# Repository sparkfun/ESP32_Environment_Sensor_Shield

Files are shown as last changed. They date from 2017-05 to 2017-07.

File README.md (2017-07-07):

SparkFun ESP32 Environment Sensor Shield
========================================

SparkFun ESP32 Environment Sensor Shield

[*SparkFun ESP32 Thing Environment Sensor Shield (DEV-14153)*](https://www.sparkfun.com/products/14153)

The SparkFun ESP32 Thing Environment Sensor Shield provides sensors and hookups for monitoring environmental conditions. While incorporating three sensors capable of measuring five different environmental variables as well as providing connections for several other sensors, this sensor shield creates the best way to make your ESP32 Thing more accurate than your local weatherman!

Repository Contents
-------------------

* **/Documentation** - Data sheets, additional product information
* **/Firmware** - Example code 
* **/Hardware** - Eagle design files (.brd, .sch)
* **/Production** - Production panel files (.brd)

Version History
---------------
* [v_H1.0](https://github.com/sparkfun/ESP32_Environment_Sensor_Shield/tree/v_H1.0) - Initial release

License Information
-------------------

This product is _**open source**_! 

Please review the LICENSE.md file for license information. 

If you have any questions or concerns on licensing, please contact techsupport@sparkfun.com.

Distributed as-is; no warranty is given.

- Your friends at SparkFun.

_<COLLABORATION CREDIT>_

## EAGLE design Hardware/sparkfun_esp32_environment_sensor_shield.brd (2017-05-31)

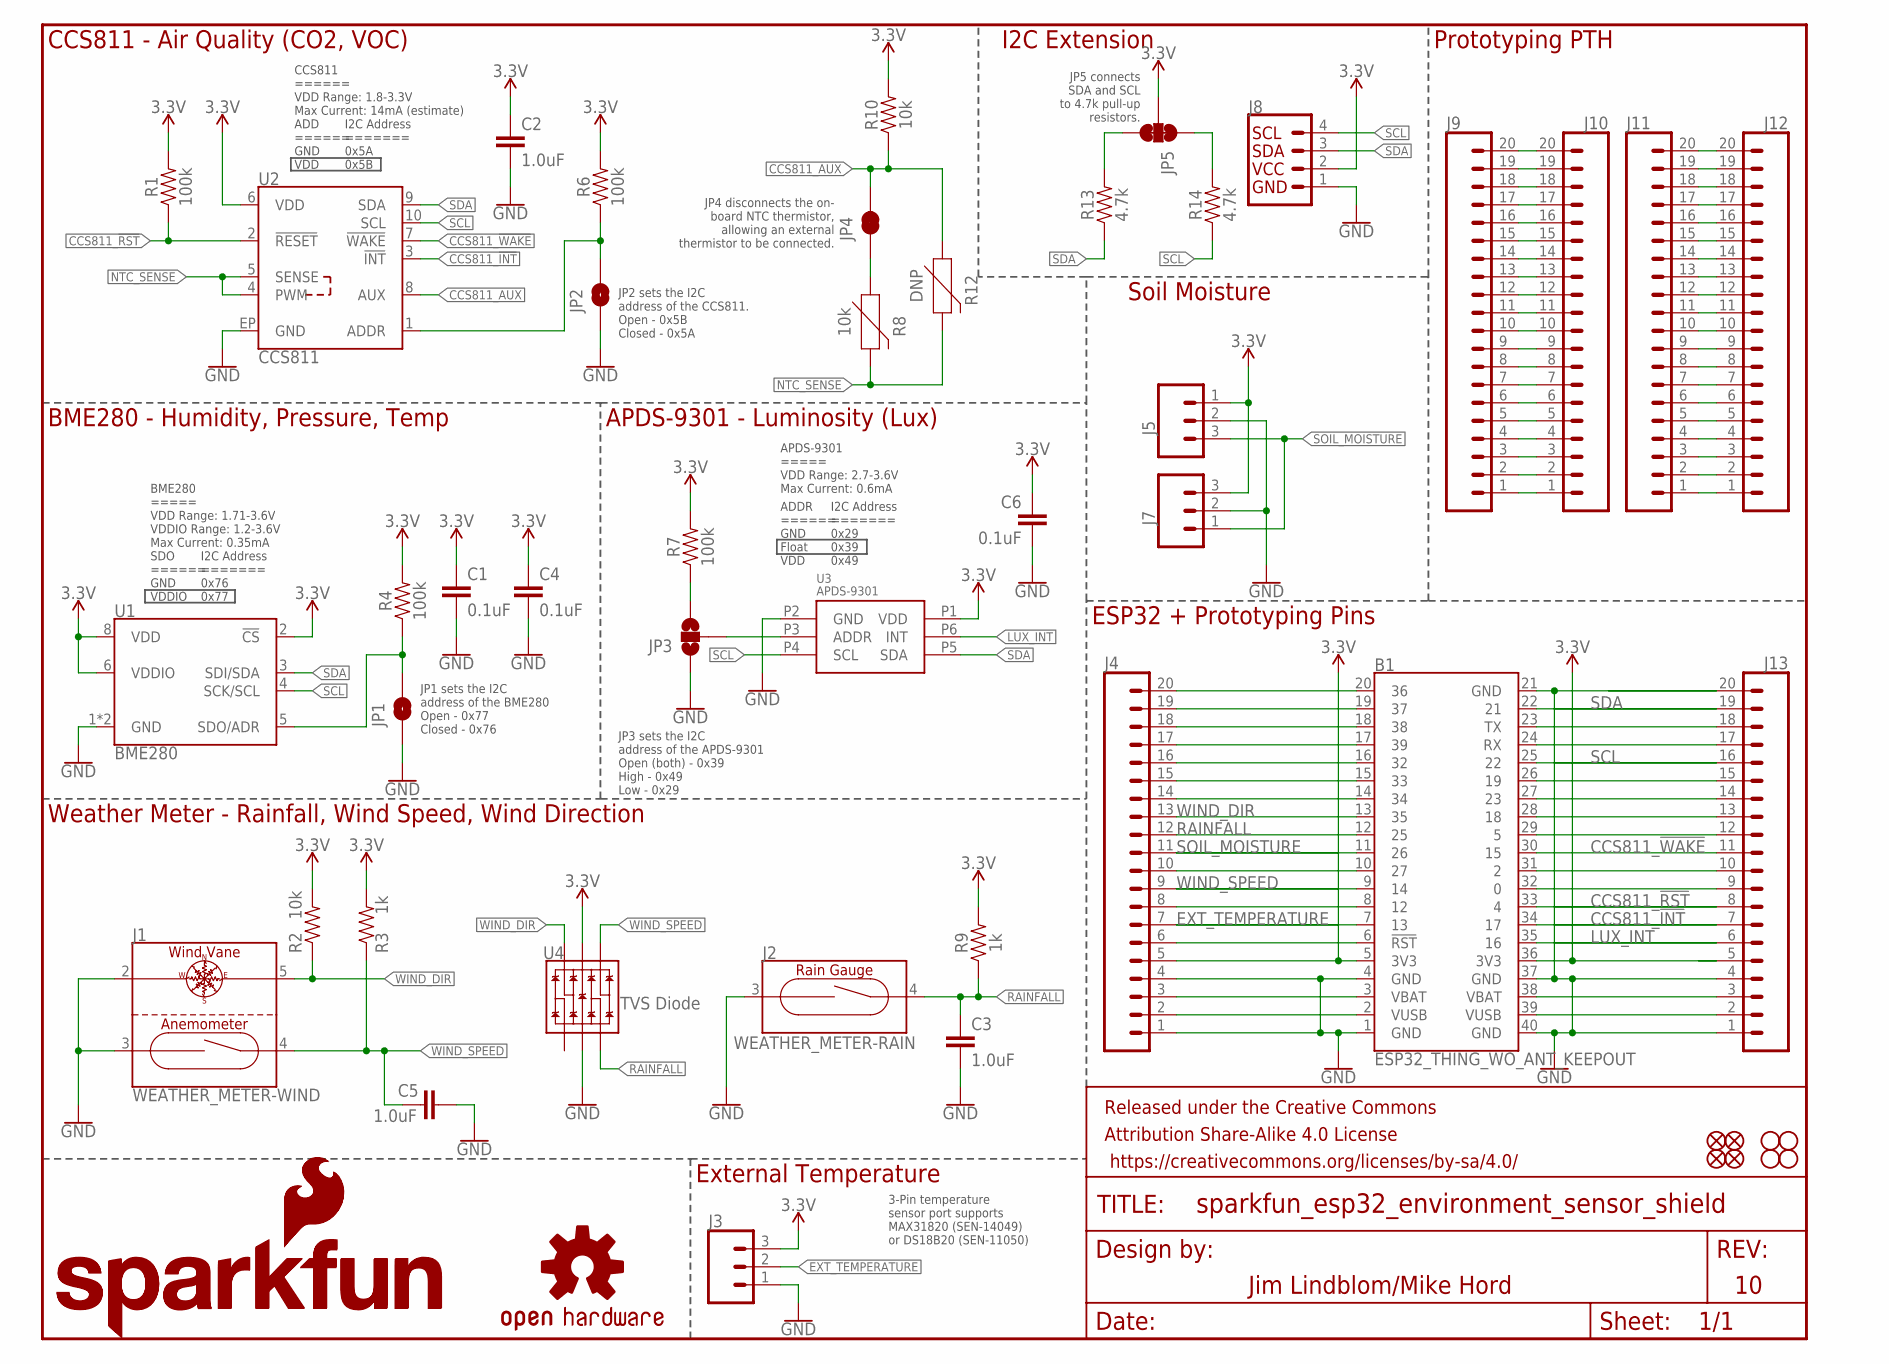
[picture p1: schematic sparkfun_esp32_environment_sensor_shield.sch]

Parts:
B1: ESP32_THING_WO_ANT_KEEPOUT; ESP32_THING_NO_ANT
C1, C4, C6: 0.1uF; 0603
C2, C3, C5: 1.0uF; 0603
FD1, FD2, FD3, FD4: FIDUCIAL1X2; FIDUCIAL-1X2
FRAME1: FRAME-LETTER; CREATIVE_COMMONS
H1, H2, H3, H4: STAND-OFF
J1: WEATHER_METER-WIND; RJ11-6
J2: WEATHER_METER-RAIN; RJ11-6
J3, J5: CONN_03; 1X03
J4, J9, J10, J11, J12, J13: CONN_20NOSILK; 1X20_NOSILK
J7: CONN_03SCREW-NS; SCREWTERMINAL-3.5MM-3-NS
J8: I2C_STANDARD; 1X04
JP1, JP2: JUMPER-SMT_2_NO_SILK; SMT-JUMPER_2_NO_SILK
JP3: JUMPER-SMT_3_NO_SILK; SMT-JUMPER_3_NO_SILK
JP4: JUMPER-SMT_2_NC_TRACE_SILK; SMT-JUMPER_2_NC_TRACE_SILK
JP5: JUMPER-SMT_3_2-NC_TRACE_SILK; SMT-JUMPER_3_2-NC_TRACE_SILK
LOGO1: SFE_LOGO_NAME.1_INCH; SFE_LOGO_NAME_.1
LOGO2: SFE_LOGO_NAME_FLAME.1_INCH; SFE_LOGO_NAME_FLAME_.1
LOGO3: SFE_LOGO_FLAME.1_INCH; SFE_LOGO_FLAME_.1
LOGO4: OSHW-LOGOS; OSHW-LOGO-S
R1, R4, R6, R7: 100k; 0603
R2, R8, R10: 10k; 0603
R3, R9: 1k; 0603
R12: DNP; AXIAL-0.1
R13, R14: 4.7k; 0603
U1: BME280; LGA-8-2.5X2.5
U2: CCS811; LGA10-2.7X4.0MM
U3: APDS-9301; CHIPLED-6
U4: TVS Diode; SOT-23-6

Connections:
3.3V: B1.5 (3V3), B1.36 (3V3), C1.1, C2.1, C4.1, C6.1, J3.3, J4.5, J5.1, J7.3, J8.2, J13.5, JP5.2, R1.2, R2.2, R3.2, R4.2, R6.2, R7.2, R9.2, R10.2, U1.2 (!CS), U1.6 (VDDIO), U1.8 (VDD), U2.6 (VDD), U3.P1 (VDD), U4.5 (VCC)
ADDR_TSL2561: JP3.2, U3.P3 (ADDR)
CCS811_!INT!: B1.34 (17), J13.7, U2.3 (!INT!)
CCS811_!RST!: B1.33 (4), J13.8, R1.1, U2.2 (!RESET!)
CCS811_!WAKE!: B1.30 (15), J13.11, U2.7 (!WAKE!)
CCS811_ADDR: JP2.2, R6.1, U2.1 (ADDR)
CCS811_AUX: JP4.2, R10.1, R12.P$1 (1), U2.8 (AUX)
EXT_TEMPERATURE: B1.7 (13), J3.2, J4.7
GND: B1.1 (GND), B1.4 (GND), B1.21 (GND), B1.37 (GND), B1.40 (GND), C1.2, C2.2, C3.2, C4.2, C5.2, C6.2, J1.2 (DIR-1), J1.3 (ANN-1), J2.3 (1), J3.1, J4.1, J4.4, J5.2, J7.2, J8.1, J13.1, J13.4, J13.20, JP1.1, JP2.1, JP3.1, U1.1 (GND), U1.7 (GND), U2.EP (GND), U3.P2 (GND), U4.2 (VSS)
LUX_INT: B1.35 (16), J13.6, U3.P6 (INT)
unnamed: JP3.3, R7.1
unnamed: JP1.2, R4.1, U1.5 (SDO/ADR)
unnamed: JP4.1, R8.1
unnamed: JP5.3, R13.2
unnamed: JP5.1, R14.2
unnamed: B1.2 (VUSB), J4.2
unnamed: B1.3 (VBAT), J4.3
unnamed: B1.6 (!RST!), J4.6
unnamed: B1.10 (27), J4.10
unnamed: B1.14 (34), J4.14
unnamed: B1.15 (33), J4.15
unnamed: B1.16 (32), J4.16
unnamed: B1.17 (39), J4.17
unnamed: B1.18 (38), J4.18
unnamed: B1.19 (37), J4.19
unnamed: B1.20 (36), J4.20
unnamed: B1.39 (VUSB), J13.2
unnamed: B1.38 (VBAT), J13.3
unnamed: B1.32 (0), J13.9
unnamed: B1.31 (2), J13.10
unnamed: B1.8 (12), J4.8
unnamed: B1.29 (5), J13.12
unnamed: B1.28 (18), J13.13
unnamed: B1.27 (23), J13.14
unnamed: B1.26 (19), J13.15
unnamed: B1.24 (RX), J13.17
unnamed: B1.23 (TX), J13.18
unnamed: J11.1, J12.1
unnamed: J11.2, J12.2
unnamed: J11.3, J12.3
unnamed: J11.4, J12.4
unnamed: J11.5, J12.5
unnamed: J11.6, J12.6
unnamed: J11.7, J12.7
unnamed: J11.8, J12.8
unnamed: J11.9, J12.9
unnamed: J11.10, J12.10
unnamed: J11.11, J12.11
unnamed: J11.12, J12.12
unnamed: J11.13, J12.13
unnamed: J11.14, J12.14
unnamed: J11.15, J12.15
unnamed: J11.16, J12.16
unnamed: J11.17, J12.17
unnamed: J11.18, J12.18
unnamed: J11.19, J12.19
unnamed: J11.20, J12.20
unnamed: J9.1, J10.1
unnamed: J9.2, J10.2
unnamed: J9.3, J10.3
unnamed: J9.4, J10.4
unnamed: J9.5, J10.5
unnamed: J9.6, J10.6
unnamed: J9.7, J10.7
unnamed: J9.8, J10.8
unnamed: J9.9, J10.9
unnamed: J9.10, J10.10
unnamed: J9.11, J10.11
unnamed: J9.12, J10.12
unnamed: J9.13, J10.13
unnamed: J9.14, J10.14
unnamed: J9.15, J10.15
unnamed: J9.16, J10.16
unnamed: J9.17, J10.17
unnamed: J9.18, J10.18
unnamed: J9.19, J10.19
unnamed: J9.20, J10.20
NTC_SENSE: R8.2, R12.P$2 (2), U2.4 (PWM), U2.5 (SENSE)
RAINFALL: B1.12 (25), C3.1, J2.4 (2), J4.12, R9.1, U4.3 (IO2)
SCL: B1.25 (22), J8.4, J13.16, R14.1, U1.4 (SCK/SCL), U2.10 (SCL), U3.P4 (SCL)
SDA: B1.22 (21), J8.3, J13.19, R13.1, U1.3 (SDI/SDA), U2.9 (SDA), U3.P5 (SDA)
SOIL_MOISTURE: B1.11 (26), J4.11, J5.3, J7.1
WIND_DIR: B1.13 (35), J1.5 (DIR2), J4.13, R2.1, U4.6 (IO4)
WIND_SPEED: B1.9 (14), C5.1, J1.4 (ANN-2), J4.9, R3.1, U4.4 (IO3)

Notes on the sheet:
APDS-9301 ===== VDD Range: 2.7-3.6V Max Current: 0.6mA
ADDR ====== GND Float VDD
I2C Address ======= 0x29 0x39 0x49
BME280 ===== VDD Range: 1.71-3.6V VDDIO Range: 1.2-3.6V Max Current: 0.35mA
SDO ====== GND VDDIO
I2C Address ======= 0x76 0x77
CCS811 ====== VDD Range: 1.8-3.3V Max Current: 14mA (estimate)
ADD ====== GND VDD
I2C Address ======= 0x5A 0x5B
CCS811 - Air Quality (CO2, VOC)
BME280 - Humidity, Pressure, Temp
APDS-9301 - Luminosity (Lux)
Weather Meter - Rainfall, Wind Speed, Wind Direction
I2C Extension
Soil Moisture
Prototyping PTH
ESP32 + Prototyping Pins
External Temperature
JP2 sets the I2C address of the CCS811. Open - 0x5B Closed - 0x5A
JP1 sets the I2C address of the BME280 Open - 0x77 Closed - 0x76
JP3 sets the I2C address of the APDS-9301 Open (both) - 0x39 High - 0x49 Low - 0x29
JP4 disconnects the on- board NTC thermistor, allowing an external thermistor to be connected.
JP5 connects SDA and SCL to 4.7k pull-up resistors.
Jim Lindblom/Mike Hord
3-Pin temperature sensor port supports MAX31820 (SEN-14049) or DS18B20 (SEN-11050)

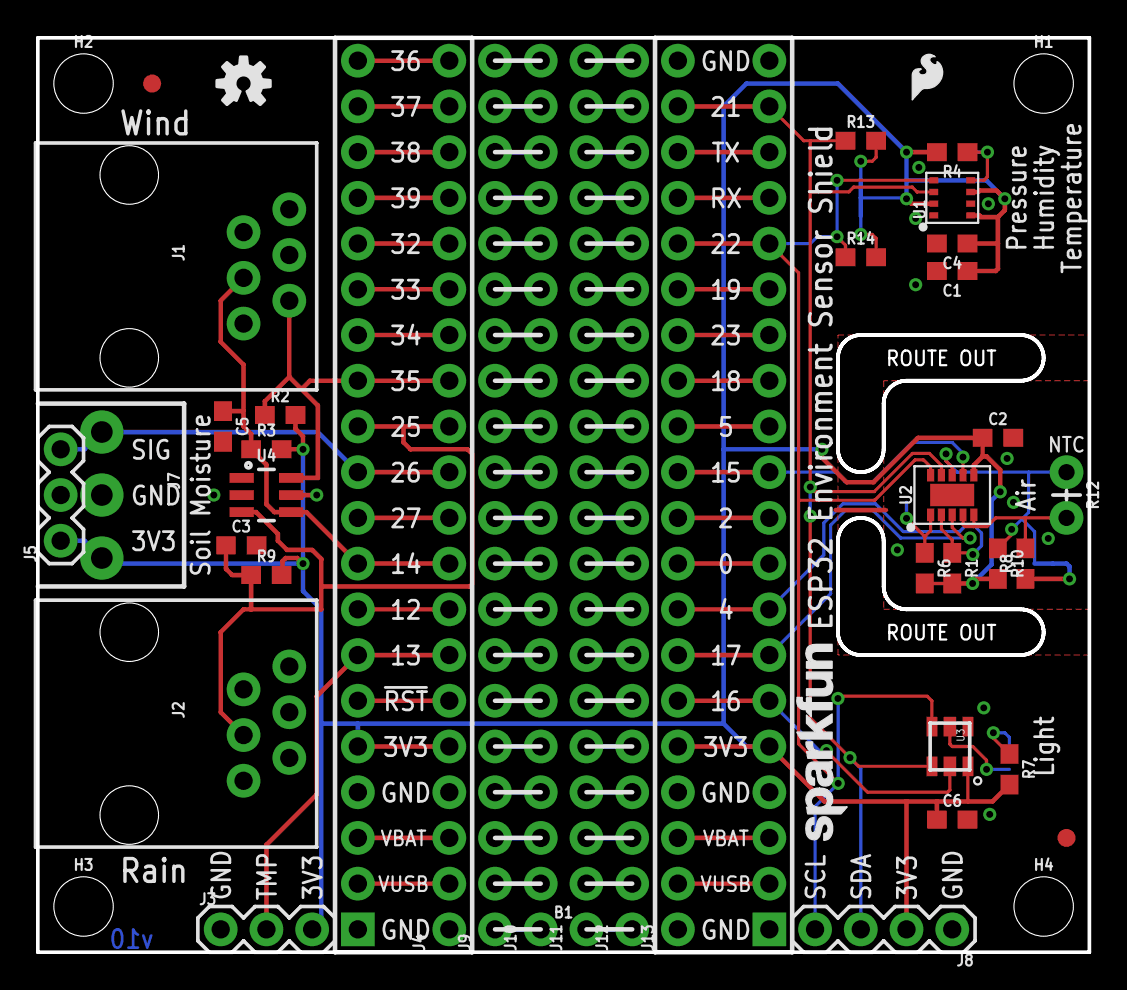
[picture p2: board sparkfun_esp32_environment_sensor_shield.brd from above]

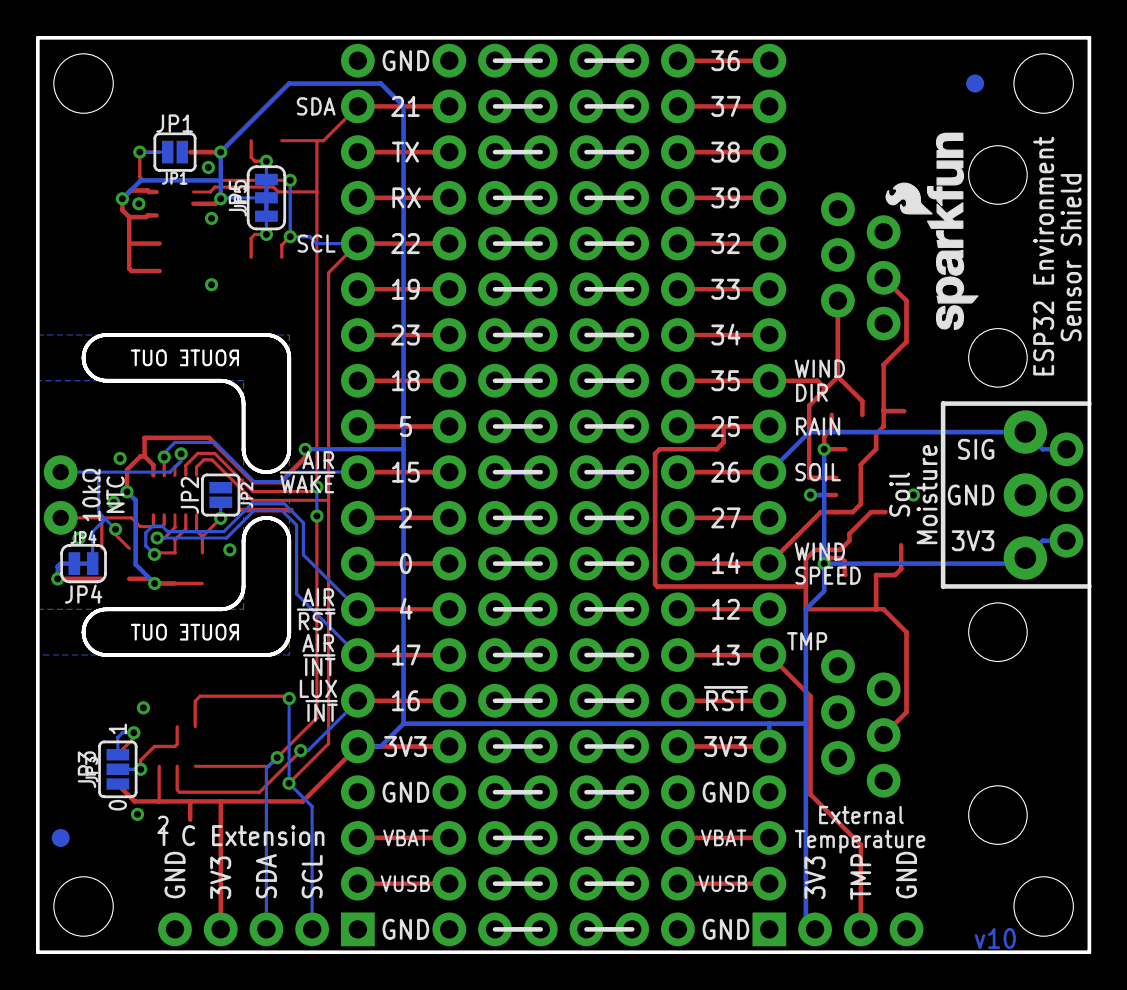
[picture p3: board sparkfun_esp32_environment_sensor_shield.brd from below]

Board: 2 copper layers, 58.4 x 50.8 mm, 53 parts (8 on the bottom side), 84 nets.

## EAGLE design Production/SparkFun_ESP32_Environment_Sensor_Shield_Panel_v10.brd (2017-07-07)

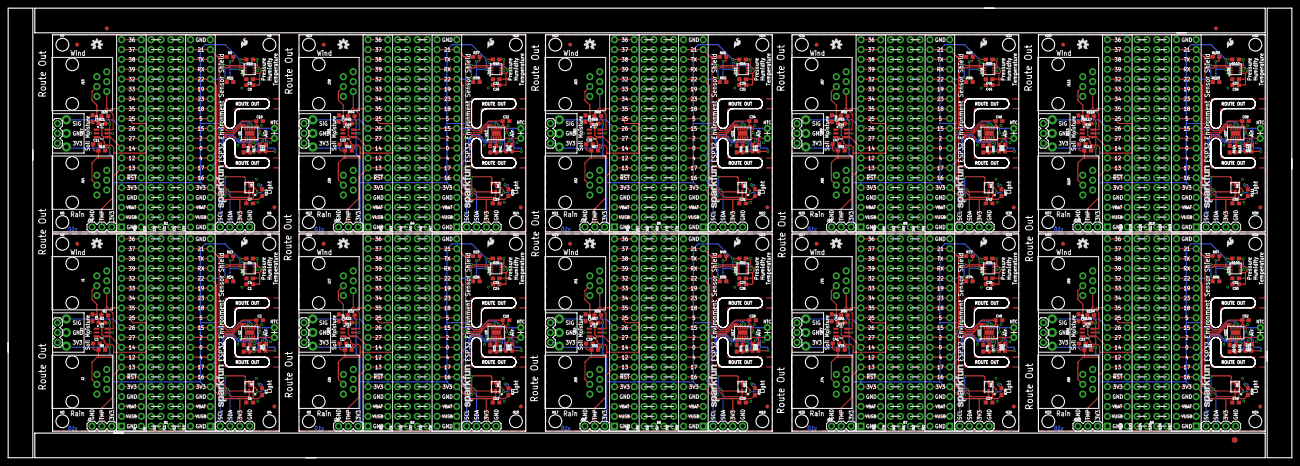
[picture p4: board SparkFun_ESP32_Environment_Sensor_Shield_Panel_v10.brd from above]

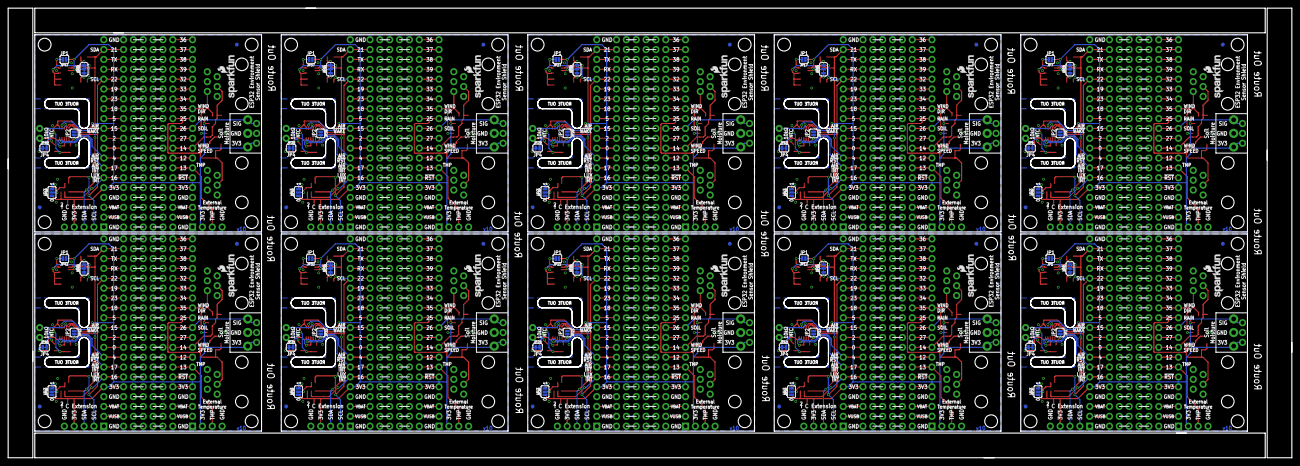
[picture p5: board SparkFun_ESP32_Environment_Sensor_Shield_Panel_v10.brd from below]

Board: 2 copper layers, 330.7 x 115.8 mm, 523 parts (80 on the bottom side), 840 nets.

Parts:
B1, B2, B3, B4, B5, B6, B7, B8, B9, B10: ESP32_THING_WO_ANT_KEEPOUT; ESP32_THING_NO_ANT
C1, C4, C6, C7, C8, C9, C13, C14, C15, C19, C20, C21, C25, C26, C27, C31, C32, C33, C37, C38, C39, C43, C44, C45, C49, C50, C51, C55, C56, C57: 0.1uF; 0603
C2, C3, C5, C10, C11, C12, C16, C17, C18, C22, C23, C24, C28, C29, C30, C34, C35, C36, C40, C41, C42, C46, C47, C48, C52, C53, C54, C58, C59, C60: 1.0uF; 0603
E$1: FIDUCIAL-1.5X3
E$7, E$8: FIDUCIAL-1X2
FD1, FD2, FD3, FD4, FD5, FD6, FD7, FD8, FD9, FD10, FD11, FD12, FD13, FD14, FD15, FD16, FD17, FD18, FD19, FD20, FD21, FD22, FD23, FD24, FD25, FD26, FD27, FD28, FD29, FD30, FD31, FD32, FD33, FD34, FD35, FD36, FD37, FD38, FD39, FD40: FIDUCIAL1X2; FIDUCIAL-1X2
H1, H2, H3, H4, H5, H6, H7, H8, H9, H10, H11, H12, H13, H14, H15, H16, H17, H18, H19, H20, H21, H22, H23, H24, H25, H26, H27, H28, H29, H30, H31, H32, H33, H34, H35, H36, H37, H38, H39, H40: STAND-OFF
J1, J15, J27, J39, J51, J63, J75, J87, J99, J111: WEATHER_METER-WIND; RJ11-6
J2, J14, J26, J38, J50, J62, J74, J86, J98, J110: WEATHER_METER-RAIN; RJ11-6
J3, J5, J16, J24, J28, J36, J40, J48, J52, J60, J64, J72, J76, J84, J88, J96, J100, J108, J112, J120: 1X03
J4, J9, J10, J11, J12, J13, J18, J19, J20, J21, J22, J23, J30, J31, J32, J33, J34, J35, J42, J43, J44, J45, J46, J47, J54, J55, J56, J57, J58, J59, J66, J67, J68, J69, J70, J71, J78, J79, J80, J81, J82, J83, J90, J91, J92, J93, J94, J95, J102, J103, J104, J105, J106, J107, J114, J115, J116, J117, J118, J119: 1X20_NOSILK
J6, J8, J25, J37, J49, J61, J73, J85, J97, J109: 1X04
J7, J17, J29, J41, J53, J65, J77, J89, J101, J113: SCREWTERMINAL-3.5MM-3-NS
JP1, JP2, JP7, JP8, JP12, JP13, JP17, JP18, JP22, JP23, JP27, JP28, JP32, JP33, JP37, JP38, JP42, JP43, JP47, JP48: SMT-JUMPER_2_NO_SILK
JP3, JP6, JP11, JP16, JP21, JP26, JP31, JP36, JP41, JP46: SMT-JUMPER_3_NO_SILK
JP4, JP9, JP14, JP19, JP24, JP29, JP34, JP39, JP44, JP49: SMT-JUMPER_2_NC_TRACE_SILK
JP5, JP10, JP15, JP20, JP25, JP30, JP35, JP40, JP45, JP50: SMT-JUMPER_3_2-NC_TRACE_SILK
LOGO1, LOGO5, LOGO9, LOGO13, LOGO17, LOGO21, LOGO25, LOGO29, LOGO33, LOGO37: SFE_LOGO_NAME.1_INCH; SFE_LOGO_NAME_.1
LOGO2, LOGO7, LOGO11, LOGO15, LOGO19, LOGO23, LOGO27, LOGO31, LOGO35, LOGO39: SFE_LOGO_NAME_FLAME.1_INCH; SFE_LOGO_NAME_FLAME_.1
LOGO3, LOGO8, LOGO12, LOGO16, LOGO20, LOGO24, LOGO28, LOGO32, LOGO36, LOGO40: SFE_LOGO_FLAME.1_INCH; SFE_LOGO_FLAME_.1
LOGO4, LOGO6, LOGO10, LOGO14, LOGO18, LOGO22, LOGO26, LOGO30, LOGO34, LOGO38: OSHW-LOGOS; OSHW-LOGO-S
R1, R4, R6, R7, R15, R16, R17, R18, R27, R28, R29, R30, R39, R40, R41, R42, R51, R52, R53, R54, R63, R64, R65, R66, R75, R76, R77, R78, R87, R88, R89, R90, R99, R100, R101, R102, R111, R112, R113, R114: 100k; 0603
R2, R8, R10, R20, R22, R23, R32, R34, R35, R44, R46, R47, R56, R58, R59, R68, R70, R71, R80, R82, R83, R92, R94, R95, R104, R106, R107, R116, R118, R119: 10k; 0603
R3, R9, R19, R21, R31, R33, R43, R45, R55, R57, R67, R69, R79, R81, R91, R93, R103, R105, R115, R117: 1k; 0603
R5, R11, R13, R14, R25, R26, R37, R38, R49, R50, R61, R62, R73, R74, R85, R86, R97, R98, R109, R110: 4.7k; 0603
R12, R24, R36, R48, R60, R72, R84, R96, R108, R120: DNP; AXIAL-0.1
U1, U6, U10, U14, U18, U22, U26, U30, U34, U38: BME280; LGA-8-2.5X2.5
U2, U5, U9, U13, U17, U21, U25, U29, U33, U37: CCS811; LGA10-2.7X4.0MM
U3, U8, U12, U16, U20, U24, U28, U32, U36, U40: APDS-9301; CHIPLED-6
U4, U7, U11, U15, U19, U23, U27, U31, U35, U39: TVS Diode; SOT-23-6

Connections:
3.3V: B1.5, B1.36, C1.1, C2.1, C4.1, C6.1, J3.3, J4.5, J5.1, J7.3, J8.2, J13.5, JP5.2, R1.2, R2.2, R3.2, R4.2, R6.2, R7.2, R9.2, R10.2, U1.2, U1.6, U1.8, U2.6, U3.P1, U4.5
3.3V1: B2.5, B2.36, C7.1, C8.1, C9.1, C10.1, J6.2, J16.1, J17.3, J18.5, J23.5, J24.3, JP10.2, R15.2, R16.2, R17.2, R18.2, R19.2, R20.2, R21.2, R22.2, U5.6, U6.2, U6.6, U6.8, U7.5, U8.P1
3.3V2: B3.5, B3.36, C13.1, C14.1, C15.1, C16.1, J25.2, J28.1, J29.3, J30.5, J35.5, J36.3, JP15.2, R27.2, R28.2, R29.2, R30.2, R31.2, R32.2, R33.2, R34.2, U9.6, U10.2, U10.6, U10.8, U11.5, U12.P1
3.3V3: B4.5, B4.36, C19.1, C20.1, C21.1, C22.1, J37.2, J40.1, J41.3, J42.5, J47.5, J48.3, JP20.2, R39.2, R40.2, R41.2, R42.2, R43.2, R44.2, R45.2, R46.2, U13.6, U14.2, U14.6, U14.8, U15.5, U16.P1
3.3V4: B5.5, B5.36, C25.1, C26.1, C27.1, C28.1, J49.2, J52.1, J53.3, J54.5, J59.5, J60.3, JP25.2, R51.2, R52.2, R53.2, R54.2, R55.2, R56.2, R57.2, R58.2, U17.6, U18.2, U18.6, U18.8, U19.5, U20.P1
3.3V5: B6.5, B6.36, C31.1, C32.1, C33.1, C34.1, J61.2, J64.1, J65.3, J66.5, J71.5, J72.3, JP30.2, R63.2, R64.2, R65.2, R66.2, R67.2, R68.2, R69.2, R70.2, U21.6, U22.2, U22.6, U22.8, U23.5, U24.P1
3.3V6: B7.5, B7.36, C37.1, C38.1, C39.1, C40.1, J73.2, J76.1, J77.3, J78.5, J83.5, J84.3, JP35.2, R75.2, R76.2, R77.2, R78.2, R79.2, R80.2, R81.2, R82.2, U25.6, U26.2, U26.6, U26.8, U27.5, U28.P1
3.3V7: B8.5, B8.36, C43.1, C44.1, C45.1, C46.1, J85.2, J88.1, J89.3, J90.5, J95.5, J96.3, JP40.2, R87.2, R88.2, R89.2, R90.2, R91.2, R92.2, R93.2, R94.2, U29.6, U30.2, U30.6, U30.8, U31.5, U32.P1
3.3V8: B9.5, B9.36, C49.1, C50.1, C51.1, C52.1, J97.2, J100.1, J101.3, J102.5, J107.5, J108.3, JP45.2, R99.2, R100.2, R101.2, R102.2, R103.2, R104.2, R105.2, R106.2, U33.6, U34.2, U34.6, U34.8, U35.5, U36.P1
3.3V9: B10.5, B10.36, C55.1, C56.1, C57.1, C58.1, J109.2, J112.1, J113.3, J114.5, J119.5, J120.3, JP50.2, R111.2, R112.2, R113.2, R114.2, R115.2, R116.2, R117.2, R118.2, U37.6, U38.2, U38.6, U38.8, U39.5, U40.P1
ADDR_TSL1: JP6.2, U8.P3
ADDR_TSL2: JP11.2, U12.P3
ADDR_TSL3: JP16.2, U16.P3
ADDR_TSL4: JP21.2, U20.P3
ADDR_TSL5: JP26.2, U24.P3
ADDR_TSL6: JP31.2, U28.P3
ADDR_TSL7: JP36.2, U32.P3
ADDR_TSL8: JP41.2, U36.P3
ADDR_TSL9: JP46.2, U40.P3
ADDR_TSL2561: JP3.2, U3.P3
CCS811_!INT!: B1.34, J13.7, U2.3
CCS811_!INT!1: B2.34, J23.7, U5.3
CCS811_!INT!2: B3.34, J35.7, U9.3
CCS811_!INT!3: B4.34, J47.7, U13.3
CCS811_!INT!4: B5.34, J59.7, U17.3
CCS811_!INT!5: B6.34, J71.7, U21.3
CCS811_!INT!6: B7.34, J83.7, U25.3
CCS811_!INT!7: B8.34, J95.7, U29.3
CCS811_!INT!8: B9.34, J107.7, U33.3
CCS811_!INT!9: B10.34, J119.7, U37.3
CCS811_!RST!: B1.33, J13.8, R1.1, U2.2
CCS811_!RST!1: B2.33, J23.8, R17.1, U5.2
CCS811_!RST!2: B3.33, J35.8, R29.1, U9.2
CCS811_!RST!3: B4.33, J47.8, R41.1, U13.2
CCS811_!RST!4: B5.33, J59.8, R53.1, U17.2
CCS811_!RST!5: B6.33, J71.8, R65.1, U21.2
CCS811_!RST!6: B7.33, J83.8, R77.1, U25.2
CCS811_!RST!7: B8.33, J95.8, R89.1, U29.2
CCS811_!RST!8: B9.33, J107.8, R101.1, U33.2
CCS811_!RST!9: B10.33, J119.8, R113.1, U37.2
CCS811_!WAKE!: B1.30, J13.11, U2.7
CCS811_!WAKE!1: B2.30, J23.11, U5.7
CCS811_!WAKE!2: B3.30, J35.11, U9.7
CCS811_!WAKE!3: B4.30, J47.11, U13.7
CCS811_!WAKE!4: B5.30, J59.11, U17.7
CCS811_!WAKE!5: B6.30, J71.11, U21.7
CCS811_!WAKE!6: B7.30, J83.11, U25.7
CCS811_!WAKE!7: B8.30, J95.11, U29.7
CCS811_!WAKE!8: B9.30, J107.11, U33.7
CCS811_!WAKE!9: B10.30, J119.11, U37.7
CCS811_ADDR: JP2.2, R6.1, U2.1
CCS811_ADDR1: JP8.2, R18.1, U5.1
CCS811_ADDR2: JP13.2, R30.1, U9.1
CCS811_ADDR3: JP18.2, R42.1, U13.1
CCS811_ADDR4: JP23.2, R54.1, U17.1
CCS811_ADDR5: JP28.2, R66.1, U21.1
CCS811_ADDR6: JP33.2, R78.1, U25.1
CCS811_ADDR7: JP38.2, R90.1, U29.1
CCS811_ADDR8: JP43.2, R102.1, U33.1
CCS811_ADDR9: JP48.2, R114.1, U37.1
CCS811_AUX: JP4.2, R10.1, R12.P$1, U2.8
CCS811_AUX1: JP9.2, R22.1, R24.P$1, U5.8
CCS811_AUX2: JP14.2, R34.1, R36.P$1, U9.8
CCS811_AUX3: JP19.2, R46.1, R48.P$1, U13.8
CCS811_AUX4: JP24.2, R58.1, R60.P$1, U17.8
CCS811_AUX5: JP29.2, R70.1, R72.P$1, U21.8
CCS811_AUX6: JP34.2, R82.1, R84.P$1, U25.8
CCS811_AUX7: JP39.2, R94.1, R96.P$1, U29.8
CCS811_AUX8: JP44.2, R106.1, R108.P$1, U33.8
CCS811_AUX9: JP49.2, R118.1, R120.P$1, U37.8
EXT_TEMPERATURE: B1.7, J3.2, J4.7
EXT_TEMPERATURE1: B2.7, J18.7, J24.2
EXT_TEMPERATURE2: B3.7, J30.7, J36.2
EXT_TEMPERATURE3: B4.7, J42.7, J48.2
EXT_TEMPERATURE4: B5.7, J54.7, J60.2
EXT_TEMPERATURE5: B6.7, J66.7, J72.2
EXT_TEMPERATURE6: B7.7, J78.7, J84.2
EXT_TEMPERATURE7: B8.7, J90.7, J96.2
EXT_TEMPERATURE8: B9.7, J102.7, J108.2
EXT_TEMPERATURE9: B10.7, J114.7, J120.2
GND: B1.1, B1.4, B1.21, B1.37, B1.40, C1.2, C2.2, C3.2, C4.2, C5.2, C6.2, J1.2, J1.3, J2.3, J3.1, J4.1, J4.4, J5.2, J7.2, J8.1, J13.1, J13.4, J13.20, JP1.1, JP2.1, JP3.1, U1.1, U1.7, U2.EP, U3.P2, U4.2
GND1: B2.1, B2.4, B2.21, B2.37, B2.40, C7.2, C8.2, C9.2, C10.2, C11.2, C12.2, J6.1, J14.3, J15.2, J15.3, J16.2, J17.2, J18.1, J18.4, J23.1, J23.4, J23.20, J24.1, JP6.1, JP7.1, JP8.1, U5.EP, U6.1, U6.7, U7.2, U8.P2
GND2: B3.1, B3.4, B3.21, B3.37, B3.40, C13.2, C14.2, C15.2, C16.2, C17.2, C18.2, J25.1, J26.3, J27.2, J27.3, J28.2, J29.2, J30.1, J30.4, J35.1, J35.4, J35.20, J36.1, JP11.1, JP12.1, JP13.1, U9.EP, U10.1, U10.7, U11.2, U12.P2
GND3: B4.1, B4.4, B4.21, B4.37, B4.40, C19.2, C20.2, C21.2, C22.2, C23.2, C24.2, J37.1, J38.3, J39.2, J39.3, J40.2, J41.2, J42.1, J42.4, J47.1, J47.4, J47.20, J48.1, JP16.1, JP17.1, JP18.1, U13.EP, U14.1, U14.7, U15.2, U16.P2
GND4: B5.1, B5.4, B5.21, B5.37, B5.40, C25.2, C26.2, C27.2, C28.2, C29.2, C30.2, J49.1, J50.3, J51.2, J51.3, J52.2, J53.2, J54.1, J54.4, J59.1, J59.4, J59.20, J60.1, JP21.1, JP22.1, JP23.1, U17.EP, U18.1, U18.7, U19.2, U20.P2
GND5: B6.1, B6.4, B6.21, B6.37, B6.40, C31.2, C32.2, C33.2, C34.2, C35.2, C36.2, J61.1, J62.3, J63.2, J63.3, J64.2, J65.2, J66.1, J66.4, J71.1, J71.4, J71.20, J72.1, JP26.1, JP27.1, JP28.1, U21.EP, U22.1, U22.7, U23.2, U24.P2
GND6: B7.1, B7.4, B7.21, B7.37, B7.40, C37.2, C38.2, C39.2, C40.2, C41.2, C42.2, J73.1, J74.3, J75.2, J75.3, J76.2, J77.2, J78.1, J78.4, J83.1, J83.4, J83.20, J84.1, JP31.1, JP32.1, JP33.1, U25.EP, U26.1, U26.7, U27.2, U28.P2
GND7: B8.1, B8.4, B8.21, B8.37, B8.40, C43.2, C44.2, C45.2, C46.2, C47.2, C48.2, J85.1, J86.3, J87.2, J87.3, J88.2, J89.2, J90.1, J90.4, J95.1, J95.4, J95.20, J96.1, JP36.1, JP37.1, JP38.1, U29.EP, U30.1, U30.7, U31.2, U32.P2
GND8: B9.1, B9.4, B9.21, B9.37, B9.40, C49.2, C50.2, C51.2, C52.2, C53.2, C54.2, J97.1, J98.3, J99.2, J99.3, J100.2, J101.2, J102.1, J102.4, J107.1, J107.4, J107.20, J108.1, JP41.1, JP42.1, JP43.1, U33.EP, U34.1, U34.7, U35.2, U36.P2
GND9: B10.1, B10.4, B10.21, B10.37, B10.40, C55.2, C56.2, C57.2, C58.2, C59.2, C60.2, J109.1, J110.3, J111.2, J111.3, J112.2, J113.2, J114.1, J114.4, J119.1, J119.4, J119.20, J120.1, JP46.1, JP47.1, JP48.1, U37.EP, U38.1, U38.7, U39.2, U40.P2
LUX_INT: B1.35, J13.6, U3.P6
LUX_INT1: B2.35, J23.6, U8.P6
LUX_INT2: B3.35, J35.6, U12.P6
LUX_INT3: B4.35, J47.6, U16.P6
LUX_INT4: B5.35, J59.6, U20.P6
LUX_INT5: B6.35, J71.6, U24.P6
LUX_INT6: B7.35, J83.6, U28.P6
LUX_INT7: B8.35, J95.6, U32.P6
LUX_INT8: B9.35, J107.6, U36.P6
LUX_INT9: B10.35, J119.6, U40.P6
unnamed: JP3.3, R7.1
unnamed: JP1.2, R4.1, U1.5
unnamed: JP4.1, R8.1
unnamed: JP5.3, R13.2
unnamed: JP5.1, R14.2
unnamed: B1.2, J4.2
unnamed: B1.3, J4.3
unnamed: B1.6, J4.6
unnamed: B1.10, J4.10
unnamed: JP6.3, R15.1
unnamed: B1.14, J4.14
unnamed: B1.15, J4.15
unnamed: B1.16, J4.16
unnamed: B1.17, J4.17
unnamed: B1.18, J4.18
unnamed: B1.19, J4.19
unnamed: B1.20, J4.20
unnamed: B1.39, J13.2
unnamed: B1.38, J13.3
unnamed: B1.32, J13.9
unnamed: B1.31, J13.10
unnamed: B1.8, J4.8
unnamed: B1.29, J13.12
unnamed: B1.28, J13.13
unnamed: B1.27, J13.14
unnamed: B1.26, J13.15
unnamed: B1.24, J13.17
unnamed: B1.23, J13.18
unnamed: J11.1, J12.1
unnamed: J11.2, J12.2
unnamed: J11.3, J12.3
unnamed: J11.4, J12.4
unnamed: J11.5, J12.5
unnamed: J11.6, J12.6
unnamed: J11.7, J12.7
unnamed: J11.8, J12.8
unnamed: J11.9, J12.9
unnamed: J11.10, J12.10
unnamed: J11.11, J12.11
unnamed: J11.12, J12.12
unnamed: J11.13, J12.13
unnamed: J11.14, J12.14
unnamed: J11.15, J12.15
unnamed: J11.16, J12.16
unnamed: J11.17, J12.17
unnamed: J11.18, J12.18
unnamed: J11.19, J12.19
unnamed: J11.20, J12.20
unnamed: J9.1, J10.1
unnamed: J9.2, J10.2
unnamed: J9.3, J10.3
unnamed: J9.4, J10.4
unnamed: J9.5, J10.5
unnamed: J9.6, J10.6
unnamed: J9.7, J10.7
unnamed: J9.8, J10.8
unnamed: J9.9, J10.9
unnamed: J9.10, J10.10
unnamed: J9.11, J10.11
unnamed: J9.12, J10.12
unnamed: J9.13, J10.13
unnamed: J9.14, J10.14
unnamed: J9.15, J10.15
unnamed: J9.16, J10.16
unnamed: J9.17, J10.17
unnamed: J9.18, J10.18
unnamed: J9.19, J10.19
unnamed: J9.20, J10.20
unnamed: JP7.2, R16.1, U6.5
unnamed: JP9.1, R23.1
unnamed: JP10.3, R5.2
unnamed: JP10.1, R11.2
unnamed: B2.2, J18.2
unnamed: B2.3, J18.3
unnamed: B2.6, J18.6
unnamed: B2.14, J18.14
unnamed: B2.15, J18.15
unnamed: B2.16, J18.16
unnamed: B2.17, J18.17
unnamed: B2.18, J18.18
unnamed: B2.19, J18.19
unnamed: B2.20, J18.20
unnamed: B2.39, J23.2
unnamed: B2.38, J23.3
unnamed: B2.32, J23.9
unnamed: B2.29, J23.12
unnamed: B2.28, J23.13
unnamed: B2.27, J23.14
unnamed: B2.26, J23.15
unnamed: B2.24, J23.17
unnamed: B2.23, J23.18
unnamed: J21.1, J22.1
unnamed: J21.2, J22.2
unnamed: J21.3, J22.3
unnamed: J21.4, J22.4
unnamed: J21.5, J22.5
unnamed: J21.6, J22.6
unnamed: J21.7, J22.7
unnamed: J21.8, J22.8
unnamed: J21.9, J22.9
unnamed: J21.10, J22.10
unnamed: J21.11, J22.11
unnamed: J21.12, J22.12
unnamed: J21.13, J22.13
unnamed: J21.14, J22.14
unnamed: J21.15, J22.15
unnamed: J21.16, J22.16
unnamed: J21.17, J22.17
unnamed: J21.18, J22.18
unnamed: J21.19, J22.19
unnamed: J21.20, J22.20
unnamed: J19.1, J20.1
unnamed: J19.2, J20.2
unnamed: J19.3, J20.3
unnamed: J19.4, J20.4
unnamed: J19.5, J20.5
unnamed: J19.6, J20.6
unnamed: J19.7, J20.7
unnamed: J19.8, J20.8
unnamed: J19.9, J20.9
unnamed: J19.10, J20.10
unnamed: J19.11, J20.11
unnamed: J19.12, J20.12
unnamed: J19.13, J20.13
unnamed: J19.14, J20.14
unnamed: J19.15, J20.15
unnamed: J19.16, J20.16
unnamed: J19.17, J20.17
unnamed: J19.18, J20.18
unnamed: J19.19, J20.19
unnamed: J19.20, J20.20
unnamed: B2.31, J23.10
unnamed: B2.8, J18.8
unnamed: B2.10, J18.10
unnamed: JP11.3, R27.1
unnamed: JP12.2, R28.1, U10.5
unnamed: JP14.1, R35.1
unnamed: JP15.3, R25.2
unnamed: JP15.1, R26.2
unnamed: B3.2, J30.2
unnamed: B3.3, J30.3
unnamed: B3.6, J30.6
unnamed: B3.14, J30.14
unnamed: B3.15, J30.15
unnamed: B3.16, J30.16
unnamed: B3.17, J30.17
unnamed: B3.18, J30.18
unnamed: B3.19, J30.19
unnamed: B3.20, J30.20
unnamed: B3.39, J35.2
unnamed: B3.38, J35.3
unnamed: B3.32, J35.9
unnamed: B3.29, J35.12
unnamed: B3.28, J35.13
unnamed: B3.27, J35.14
unnamed: B3.26, J35.15
unnamed: B3.24, J35.17
unnamed: B3.23, J35.18
unnamed: J33.1, J34.1
unnamed: J33.2, J34.2
unnamed: J33.3, J34.3
unnamed: J33.4, J34.4
unnamed: J33.5, J34.5
unnamed: J33.6, J34.6
unnamed: J33.7, J34.7
unnamed: J33.8, J34.8
unnamed: J33.9, J34.9
unnamed: J33.10, J34.10
unnamed: J33.11, J34.11
unnamed: J33.12, J34.12
unnamed: J33.13, J34.13
unnamed: J33.14, J34.14
unnamed: J33.15, J34.15
unnamed: J33.16, J34.16
unnamed: J33.17, J34.17
unnamed: J33.18, J34.18
unnamed: J33.19, J34.19
unnamed: J33.20, J34.20
unnamed: J31.1, J32.1
unnamed: J31.2, J32.2
unnamed: J31.3, J32.3
unnamed: J31.4, J32.4
unnamed: J31.5, J32.5
unnamed: J31.6, J32.6
unnamed: J31.7, J32.7
unnamed: J31.8, J32.8
unnamed: J31.9, J32.9
unnamed: J31.10, J32.10
unnamed: J31.11, J32.11
unnamed: J31.12, J32.12
unnamed: J31.13, J32.13
unnamed: J31.14, J32.14
unnamed: J31.15, J32.15
unnamed: J31.16, J32.16
unnamed: J31.17, J32.17
unnamed: J31.18, J32.18
unnamed: J31.19, J32.19
unnamed: J31.20, J32.20
unnamed: B3.31, J35.10
unnamed: B3.8, J30.8
unnamed: B3.10, J30.10
unnamed: JP16.3, R39.1
unnamed: JP17.2, R40.1, U14.5
unnamed: JP19.1, R47.1
unnamed: JP20.3, R37.2
unnamed: JP20.1, R38.2
unnamed: B4.2, J42.2
unnamed: B4.3, J42.3
unnamed: B4.6, J42.6
unnamed: B4.14, J42.14
unnamed: B4.15, J42.15
unnamed: B4.16, J42.16
unnamed: B4.17, J42.17
unnamed: B4.18, J42.18
unnamed: B4.19, J42.19
unnamed: B4.20, J42.20
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

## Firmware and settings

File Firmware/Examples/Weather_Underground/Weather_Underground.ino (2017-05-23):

    #include <SparkFunCCS811.h>
    #include "SparkFunBME280.h"
    #include "Wire.h"
    #include <Sparkfun_APDS9301_Library.h>
    #include <WiFi.h>
    
    BME280 bme;
    CCS811 ccs(0x5B);
    APDS9301 apds;
    
    // Variables for wifi server setup 
    const char* ssid     = "ssid_goes_here";
    const char* password = "password_goes_here"; 
    String ID = "station_id_goes_here";
    String key = "wunderground_key_goes_here";  
    WiFiClient client;
    const int httpPort = 80;
    const char* host = "weatherstation.wunderground.com";
    
    // Variables and constants used in calculating the windspeed.
    volatile unsigned long timeSinceLastTick = 0;
    volatile unsigned long lastTick = 0;
    
    // Variables and constants used in tracking rainfall
    #define S_IN_DAY   86400
    #define S_IN_HR     3600
    #define NO_RAIN_SAMPLES 2000
    volatile long rainTickList[NO_RAIN_SAMPLES];
    volatile int rainTickIndex = 0;
    volatile int rainTicks = 0;
    int rainLastDay = 0;
    int rainLastHour = 0;
    int rainLastHourStart = 0;
    int rainLastDayStart = 0;
    long secsClock = 0;
    
    String windDir = "";
    float windSpeed = 0.0;
    
    // Pin assignment definitions
    #define WIND_SPD_PIN 14
    #define RAIN_PIN     25
    #define WIND_DIR_PIN 35
    #define AIR_RST      4
    #define AIR_WAKE     15
    #define DONE_LED     5
    
    void setup() 
    {
      delay(5);    // The CCS811 wants a brief delay after startup.
      Serial.begin(115200);
      Wire.begin();

      pinMode(DONE_LED, OUTPUT);
      digitalWrite(DONE_LED, LOW);
    
      // Wind speed sensor setup. The windspeed is calculated according to the number
      //  of ticks per second. Timestamps are captured in the interrupt, and then converted
      //  into mph. 
      pinMode(WIND_SPD_PIN, INPUT);     // Wind speed sensor
      attachInterrupt(digitalPinToInterrupt(WIND_SPD_PIN), windTick, RISING);
    
      // Rain sesnor setup. Rainfall is tracked by ticks per second, and timestamps of
      //  ticks are tracked so rainfall can be "aged" (i.e., rain per hour, per day, etc)
      pinMode(RAIN_PIN, INPUT);     // Rain sensor
      attachInterrupt(digitalPinToInterrupt(RAIN_PIN), rainTick, RISING);
      // Zero out the timestamp array.
      for (int i = 0; i < NO_RAIN_SAMPLES; i++) rainTickList[i] = 0;
    
      // BME280 sensor setup - these are fairly conservative settings, suitable for
      //  most applications. For more information regarding the settings available
      //  for the BME280, see the example sketches in the BME280 library.
      bme.settings.commInterface = I2C_MODE;
      bme.settings.I2CAddress = 0x77;
      bme.settings.runMode = 3;
      bme.settings.tStandby = 0;
      bme.settings.filter = 0;
      bme.settings.tempOverSample = 1;
      bme.settings.pressOverSample = 1;
      bme.settings.humidOverSample = 1;
      bme.begin();
    
      // CCS811 sensor setup.
      pinMode(AIR_WAKE, OUTPUT);
      digitalWrite(AIR_WAKE, LOW);
      pinMode(AIR_RST, OUTPUT);
      digitalWrite(AIR_RST, LOW);
      delay(10);
      digitalWrite(AIR_RST, HIGH);
      delay(100);
      ccs.begin();
    
      // APDS9301 sensor setup. Leave the default settings in place.
      apds.begin(0x39);


      // Connect to WiFi network
      Serial.print("Connecting to ");
      Serial.println(ssid);
    
      WiFi.begin(ssid, password);
    
      while (WiFi.status() != WL_CONNECTED) {
          delay(500);
          Serial.print(".");
      }
      Serial.println("");
      Serial.println("WiFi connected");
      Serial.println("IP address: ");
      Serial.println(WiFi.localIP());

      // Visible WiFi connected signal for when serial isn't connected
      digitalWrite(DONE_LED, HIGH);
    }
    
    void loop() 
    {
      static unsigned long outLoopTimer = 0;
      static unsigned long wundergroundUpdateTimer = 0;
      static unsigned long clockTimer = 0;
      static unsigned long tempMSClock = 0;
    
      // Create a seconds clock based on the millis() count. We use this
      //  to track rainfall by the second. We've done this because the millis()
      //  count overflows eventually, in a way that makes tracking time stamps
      //  very difficult.
      tempMSClock += millis() - clockTimer;
      clockTimer = millis();
      while (tempMSClock >= 1000)
      {
        secsClock++;
        tempMSClock -= 1000;
      }
      
      // This is a once-per-second timer that calculates and prints off various
      //  values from the sensors attached to the system.
      if (millis() - outLoopTimer >= 2000)
      {
        outLoopTimer = millis();
    
        Serial.print("\nTimestamp: ");
        Serial.println(secsClock);
     
        // Windspeed calculation, in mph. timeSinceLastTick gets updated by an
        //  interrupt when ticks come in from the wind speed sensor.
        if (timeSinceLastTick != 0) windSpeed = 1000.0/timeSinceLastTick;
        Serial.print("Windspeed: ");
        Serial.print(windSpeed*1.492);
        Serial.println(" mph");
      
        // Update temperature. This also updates compensation values used to
        //  calculate other parameters.
        Serial.print("Temperature: ");
        Serial.print(bme.readTempF(), 2);
        Serial.println(" degrees F");
      
        // Display relative humidity.
        Serial.print("%RH: ");
        Serial.print(bme.readFloatHumidity(), 2);
        Serial.println(" %");
    
        // Display pressure.
        Serial.print("Pres: ");
        Serial.print(bme.readFloatPressure() * 0.0002953);
        Serial.println(" in");
    
        // Calculate the wind direction and display it as a string.
        Serial.print("Wind dir: ");
        windDirCalc(analogRead(WIND_DIR_PIN));
        Serial.print("  ");
        Serial.println(windDir);
    
        // Calculate and display rainfall totals.
        Serial.print("Rainfall last hour: ");
        Serial.println(float(rainLastHour)*0.011, 3);
        Serial.print("Rainfall last day: ");
        Serial.println(float(rainLastDay)*0.011, 3);
        Serial.print("Rainfall to date: ");
        Serial.println(float(rainTicks)*0.011, 3);
    
        // Trigger the CCS811's internal update procedure, then
        //  dump the values to the serial port.
        ccs.readAlgorithmResults();
    
        Serial.print("CO2: ");
        Serial.println(ccs.getCO2());
    
        Serial.print("tVOC: ");
        Serial.println(ccs.getTVOC());
    
        Serial.print("Luminous flux: ");
        Serial.println(apds.readLuxLevel(),6);
    
        // Calculate the amount of rain in the last day and hour.
        rainLastHour = 0;
        rainLastDay = 0;
        // If there are any captured rain sensor ticks...
        if (rainTicks > 0)
        {
          // Start at the end of the list. rainTickIndex will always be one greater
          //  than the number of captured samples.
          int i = rainTickIndex-1;
    
          // Iterate over the list and count up the number of samples that have been
          //  captured with time stamps in the last hour.
          while ((rainTickList[i] >= secsClock - S_IN_HR) && rainTickList[i] != 0)
          {
            i--;
            if (i < 0) i = NO_RAIN_SAMPLES-1;
            rainLastHour++;
          }
    
          // Repeat the process, this time over days.
          i = rainTickIndex-1;
          while ((rainTickList[i] >= secsClock - S_IN_DAY) && rainTickList[i] != 0)
          {
            i--;
            if (i < 0) i = NO_RAIN_SAMPLES-1;
            rainLastDay++;
          }
          rainLastDayStart = i;
        }
      }
    
      // Update wunderground once every sixty seconds.
      if (millis() - wundergroundUpdateTimer >= 60000)
      {
    
      wundergroundUpdateTimer = millis();
        // Set up the generic use-every-time part of the URL
        String url = "/weatherstation/updateweatherstation.php";
        url += "?ID=";
        url += ID;
        url += "&PASSWORD=";
        url += key;
        url += "&dateutc=now&action=updateraw";
    
        // Now let's add in the data that we've collected from our sensors
        // Start with rain in last hour/day
        url += "&rainin=";
        url += rainLastHour;
        url += "&dailyrainin=";
        url += rainLastDay;
    
        // Next let's do wind
        url += "&winddir=";
        url += windDir;
        url += "&windspeedmph=";
        url += windSpeed;
    
        // Now for temperature, pressure and humidity.
        url += "&tempf=";
        url += bme.readTempF();
        url += "&humidity=";
        url += bme.readFloatHumidity();
        url += "&baromin=";
        float baromin = 0.0002953 * bme.readFloatPressure();
        url += baromin;
    
        // Connnect to Weather Underground. If the connection fails, return from
        //  loop and start over again.
        if (!client.connect(host, httpPort))
        {
          Serial.println("Connection failed");
          return;
        }
        else
        {
          Serial.println("Connection succeeded");
        }
    
        // Issue the GET command to Weather Underground to post the data we've 
        //  collected.
        client.print(String("GET ") + url + " HTTP/1.1\r\n" +
                     "Host: " + host + "\r\n" +
                     "Connection: close\r\n\r\n");
    
        // Give Weather Underground five seconds to reply.
        unsigned long timeout = millis();
        while (client.available() == 0) 
        {
          if (millis() - timeout > 5000) 
          {
              Serial.println(">>> Client Timeout !");
              client.stop();
              return;
          }
        }
    
        // Read the response from Weather Underground and print it to the console.
        while(client.available()) 
        {
          String line = client.readStringUntil('\r');
          Serial.print(line);
        }
      }
    }
    
    // Keep track of when the last tick came in on the wind sensor.
    void windTick(void)
    {
      timeSinceLastTick = millis() - lastTick;
      lastTick = millis();
    }
    
    // Capture timestamp of when the rain sensor got tripped.
    void rainTick(void)
    {
      rainTickList[rainTickIndex++] = secsClock;
      if (rainTickIndex == NO_RAIN_SAMPLES) rainTickIndex = 0;
      rainTicks++;
    }
    
    // For the purposes of this calculation, 0deg is when the wind vane
    //  is pointed at the anemometer. The angle increases in a clockwise
    //  manner from there.
    void windDirCalc(int vin)
    {
      if      (vin < 150) windDir="202.5";
      else if (vin < 300) windDir = "180";
      else if (vin < 400) windDir = "247.5";
      else if (vin < 600) windDir = "225";
      else if (vin < 900) windDir = "292.5";
      else if (vin < 1100) windDir = "270";
      else if (vin < 1500) windDir = "112.5";
      else if (vin < 1700) windDir = "135";
      else if (vin < 2250) windDir = "337.5";
      else if (vin < 2350) windDir = "315";
      else if (vin < 2700) windDir = "67.5";
      else if (vin < 3000) windDir = "90";
      else if (vin < 3200) windDir = "22.5";
      else if (vin < 3400) windDir = "45";
      else if (vin < 4000) windDir = "0";
      else windDir = "0";
    }

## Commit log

2017-01-23 Initial commit of hardware.
    [sparkfun_esp32_environment_sensor_shield.brd, sparkfun_esp32_environment_sensor_shield.sch]
2017-01-23 Schematic cleanup. Bussing inner prototyping pins together.
    [sparkfun_esp32_environment_sensor_shield.brd, sparkfun_esp32_environment_sensor_shield.sch]
2017-01-23 Connecting CCS811 RST pin to ESP32.
    [sparkfun_esp32_environment_sensor_shield.brd, sparkfun_esp32_environment_sensor_shield.sch]
2017-01-23 Labeling in-use pins on bottom side.
    [sparkfun_esp32_environment_sensor_shield.brd]
2017-01-23 Tweaking CCS811 route out.
    [sparkfun_esp32_environment_sensor_shield.brd]
2017-01-24 Revising weather meter circuits after tests with ESP32 Thing.
    [sparkfun_esp32_environment_sensor_shield.brd, sparkfun_esp32_environment_sensor_shield.sch]
2017-01-25 Adding TVS diode to weather meter signals.
    [sparkfun_esp32_environment_sensor_shield.brd, sparkfun_esp32_environment_sensor_shield.sch]
2017-01-25 Post-review fixes: CCS811 paste, spell check
    - Reduced size of CCS811's exposed pad paste aperature
    - Fixed anemometer spelling
    - Changed "Gas" to "Air" labels
    - Clean up schematic
    [sparkfun_esp32_environment_sensor_shield.brd, sparkfun_esp32_environment_sensor_shield.sch]
2017-01-26 Minor adjustments after running Engineer checklist.
    [sparkfun_esp32_environment_sensor_shield.brd, sparkfun_esp32_environment_sensor_shield.sch]
2017-01-26 Adjustin silkscreen, adding measures to RJ11 jacks, screw terminals.
    [sparkfun_esp32_environment_sensor_shield.brd, sparkfun_esp32_environment_sensor_shield.sch]
2017-03-21 Replaced TLS2561 sensor with APDS-9301
    [sparkfun_esp32_environment_sensor_shield.brd, sparkfun_esp32_environment_sensor_shield.sch]
2017-03-22 Feedback from review
    [sparkfun_esp32_environment_sensor_shield.brd, sparkfun_esp32_environment_sensor_shield.sch]
2017-03-28 Chg rev to 02
    [sparkfun_esp32_environment_sensor_shield.brd, sparkfun_esp32_environment_sensor_shield.sch]
2017-03-29 Fix issues from review
    [sparkfun_esp32_environment_sensor_shield.brd, sparkfun_esp32_environment_sensor_shield.sch]
2017-04-18 Changes after review of 02 - Change i2c addr info for apds-9301 - Change pin rain sensor is attached to - Add debounce caps to rain sensor and anemometer - Fix APDS-9301 footprint
    [sparkfun_esp32_environment_sensor_shield.brd, sparkfun_esp32_environment_sensor_shield.sch]
2017-04-19 Minor cosmetic changes from review
    [sparkfun_esp32_environment_sensor_shield.brd, sparkfun_esp32_environment_sensor_shield.sch]
2017-05-23 Changes from review
    [sparkfun_esp32_environment_sensor_shield.brd, sparkfun_esp32_environment_sensor_shield.sch]
2017-05-30 created panel v10
    [SparkFun_esp32_Environment_Sensor_Shield_Panel_v10.brd]
2017-05-31 removing bad panel
    [SparkFun_esp32_Environment_Sensor_Shield_Panel_v10.brd]
2017-05-31 Removed restrict layers on antenna for panelization
    [sparkfun_esp32_environment_sensor_shield.brd, sparkfun_esp32_environment_sensor_shield.sch]
2017-05-31 re-created panel v10
    [SparkFun_ESP32_Environment_Sensor_Shield_Panel_v10.brd]

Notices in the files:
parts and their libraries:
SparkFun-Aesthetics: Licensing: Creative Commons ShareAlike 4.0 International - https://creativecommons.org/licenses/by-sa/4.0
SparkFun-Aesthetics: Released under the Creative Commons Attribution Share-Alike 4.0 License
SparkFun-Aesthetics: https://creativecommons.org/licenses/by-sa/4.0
